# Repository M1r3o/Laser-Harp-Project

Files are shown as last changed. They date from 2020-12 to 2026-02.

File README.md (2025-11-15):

# Laser-Harp-Project
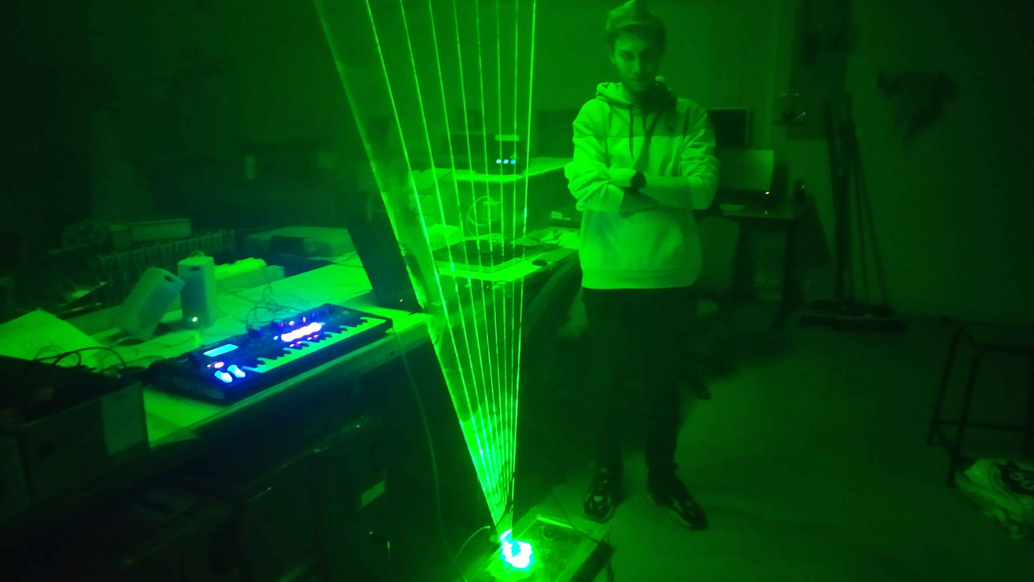
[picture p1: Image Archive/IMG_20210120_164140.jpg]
Laser Harp


This project was made in collaboration with Frederic_Wauters, Franck Morisseau A.K.A Genesis and Thomas Avisse, they helped me to understand the principle work of the laser harp . 

 This repository is a gather of all of my research, test , version, of Laser Harp     

/!\ The Light of Laser is very dangerous for the eyes, protect your eyes with a specific goggles /!\  

 This repository may not be complete but the main, schematics, code, plans and GERBER file is here to help you in this project.  

Disclaimer : some or any option ( example : strings vibration, RGB parametrable laser beam and the hand height) 
are inspired by french Laser Harp team : [there Laser Harp website](https://www.harpelaser.com) 
designed and conceived by (Franck Morisseau, Laurent Ma , and Other Laurent) 
But our electrical schematics, program, and pcb are not in relation with him and their team, just some option are inspired by their work 

Disclaimer #2 : WE ARE NOT RESPONSIBLE FOR BAD USAGE OF YOUR LASER, AND THIS REPOSITORY ARE NOT DELIVERED WITH ANY WARRANTY !!!

Thanks 

LH-Arduino Team 

## Demo of Laser Harp
### [Demo Laser Harp](https://youtu.be/7bUMFFDsR9I)

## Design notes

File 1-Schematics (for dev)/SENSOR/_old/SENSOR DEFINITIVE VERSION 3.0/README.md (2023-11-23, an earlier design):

For the sensor you have two choice (with same electronic board) 
- you can just use the dev version (but not sure their work correctly)
- or you can use the functionnal version which was tested (you need to print functionnal and dev version to compare which compoenent are removed, modify, or connected to the ground)

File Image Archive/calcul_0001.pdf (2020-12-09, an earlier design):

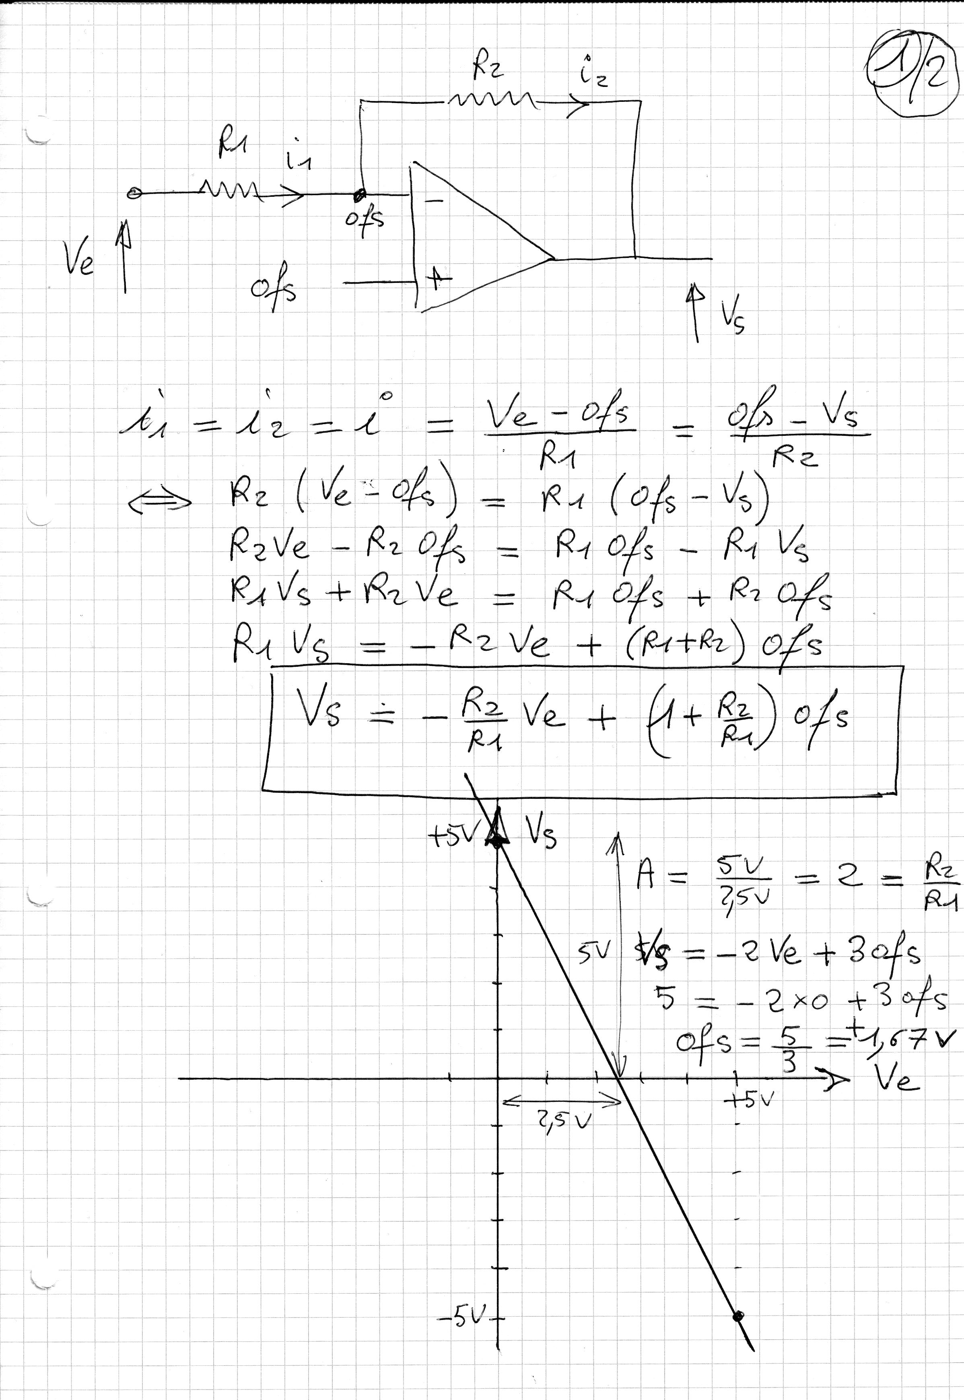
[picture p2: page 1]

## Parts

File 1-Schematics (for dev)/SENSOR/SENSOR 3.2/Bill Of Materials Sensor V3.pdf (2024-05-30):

## Bill Of Materials for Sensor V3

Design Title | Sensor V3

### Author Document Number Revision

Design Created | jeudi 28 avril 2022
Design Last Modified vendredi 23 février 2024

### Total Parts In Design 44

0 Modules
Quantity | References | Value | Stock Code | Unit Cost
Sub-totals: | | | | €0,00
22 Capacitors
Quantity | References | Value | Stock Code | Unit Cost
1 | C1 | 20pF
1 | C2 | 500nF
1 | C3 | 1nF
1 | C4 | 150nF
1 | C5 | 530nF
14 | C6-C7,C11-C22 | 100nF
3 | C8-C10 | 10uF
Sub-totals: | | | | €0,00
11 Resistors
Quantity | References | Value | Stock Code | Unit Cost
1 | R1 | 200k | M9K1
1 | R2 | 9k1 | M9K1
1 | R3 | 120k | M9K1
1 | R4 | 10k | M9K1
2 | R5-R6 | 1k | M9K1
3 | R7-R9 | 1K | M9K1
1 | R10 | 100K | M9K1
1 | R11 | 1M | M9K1
Sub-totals: | | | | €0,00
5 Integrated Circuits
Quantity | References | Value | Stock Code | Unit Cost
3 | U1,U4-U5 | TL082
1 | U2 | LM393
1 | U3 | ICL7660
Sub-totals: | | | | €0,00
0 Transistors
Quantity | References | Value | Stock Code | Unit Cost
Sub-totals: | | | | €0,00
3 Diodes
Quantity | References | Value | Stock Code | Unit Cost
1 | D1 | SLD70
1 | D3 | 1N4740A
1 | D4 | DIODE-SC
Sub-totals: | | | | €0,00
3 Miscellaneous
Quantity | References | Value | Stock Code | Unit Cost
1 | DB1 | DB9
1 | J1 | 27630302RP2 | NorComp 27630302RP2
1 | RV1 | 200K | Digikey 3252W-204LF-ND
Sub-totals: | | | | €0,00

Tot

als: | €0,0
| 0

ve

n

dre

di

2

| 3 fé vri
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
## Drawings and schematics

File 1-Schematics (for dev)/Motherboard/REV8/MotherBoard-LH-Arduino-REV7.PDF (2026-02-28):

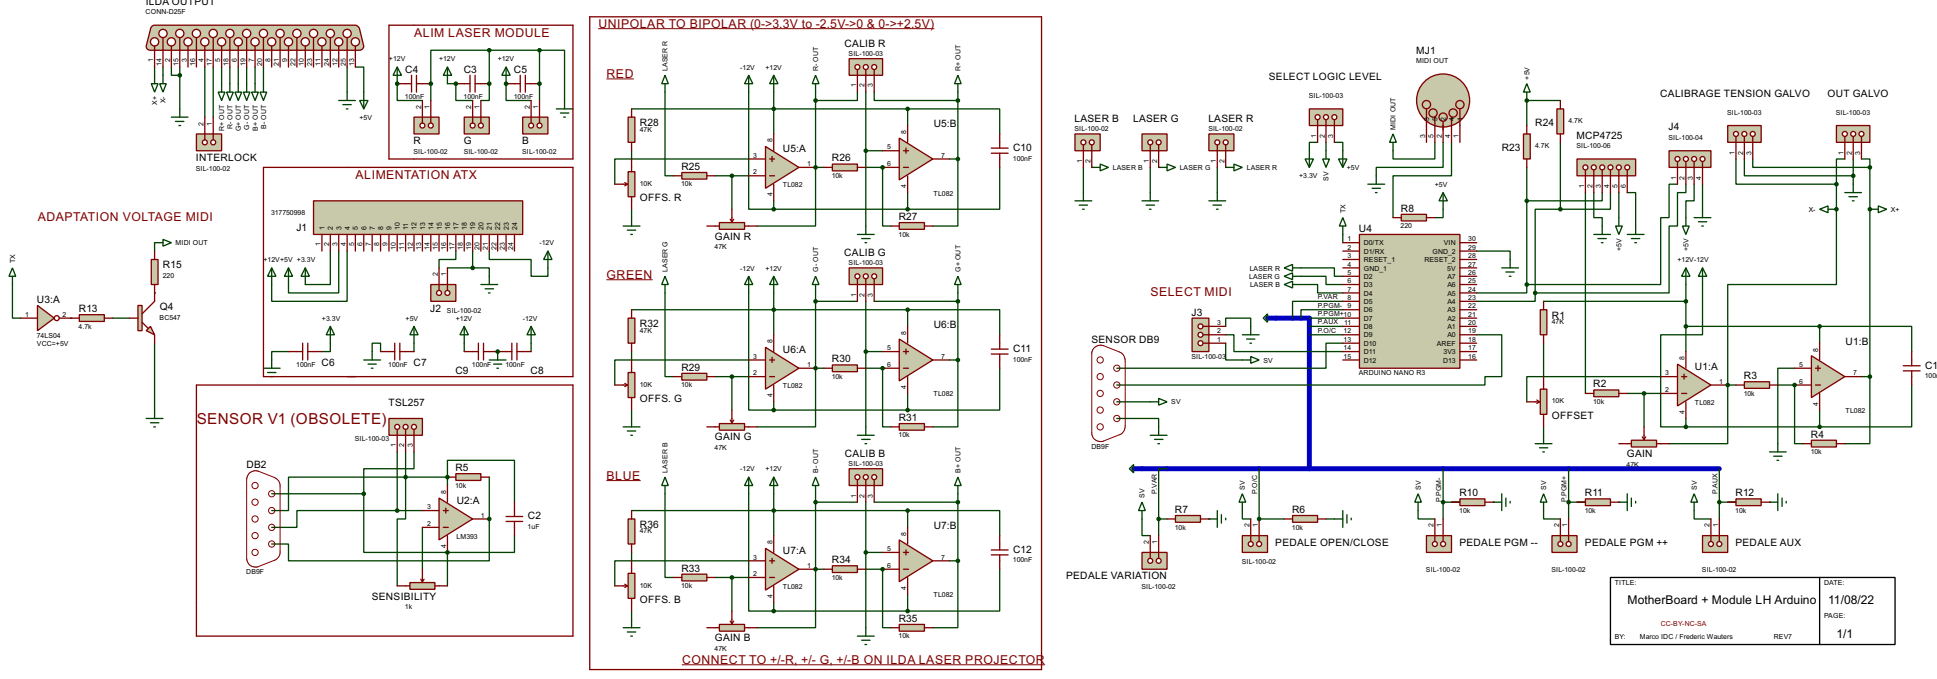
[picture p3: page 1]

UNIPOLAR TO BIPOLAR (0->3.3V to -2.5V->0 & 0->+2.5V)

GAIN B
CONNECT TO +/-R, +/- G, +/-B ON ILDA LASER PROJECTOR

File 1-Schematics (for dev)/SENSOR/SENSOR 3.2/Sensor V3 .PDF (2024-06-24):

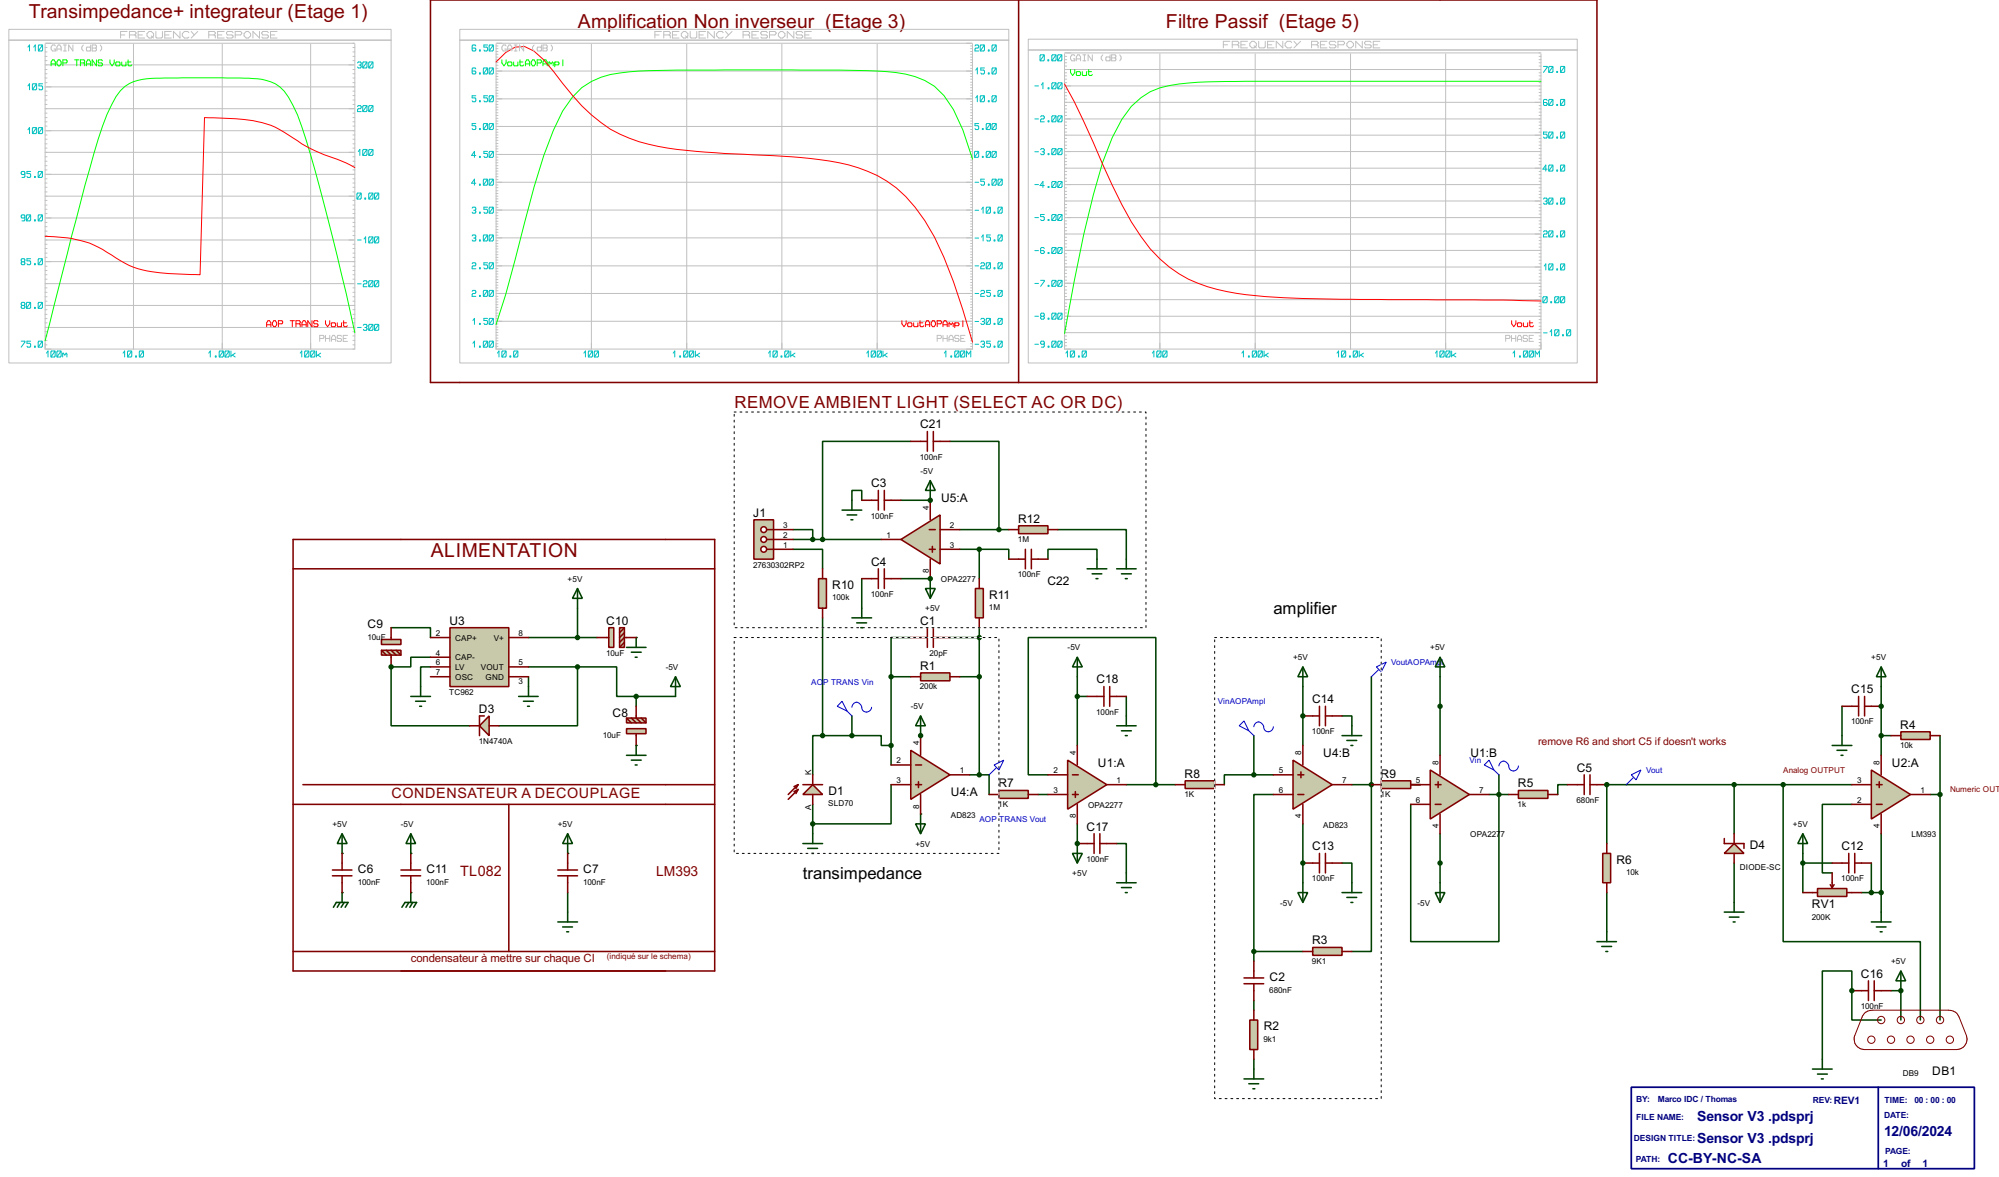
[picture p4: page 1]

REMOVE AMBIENT LIGHT (SELECT AC OR DC)

remove R6 and short C5 if doesn't works

(indiqué sur le schema)

condensateur à mettre sur chaque CI

DESIGN TITLE:Sensor V3 .pdsprj

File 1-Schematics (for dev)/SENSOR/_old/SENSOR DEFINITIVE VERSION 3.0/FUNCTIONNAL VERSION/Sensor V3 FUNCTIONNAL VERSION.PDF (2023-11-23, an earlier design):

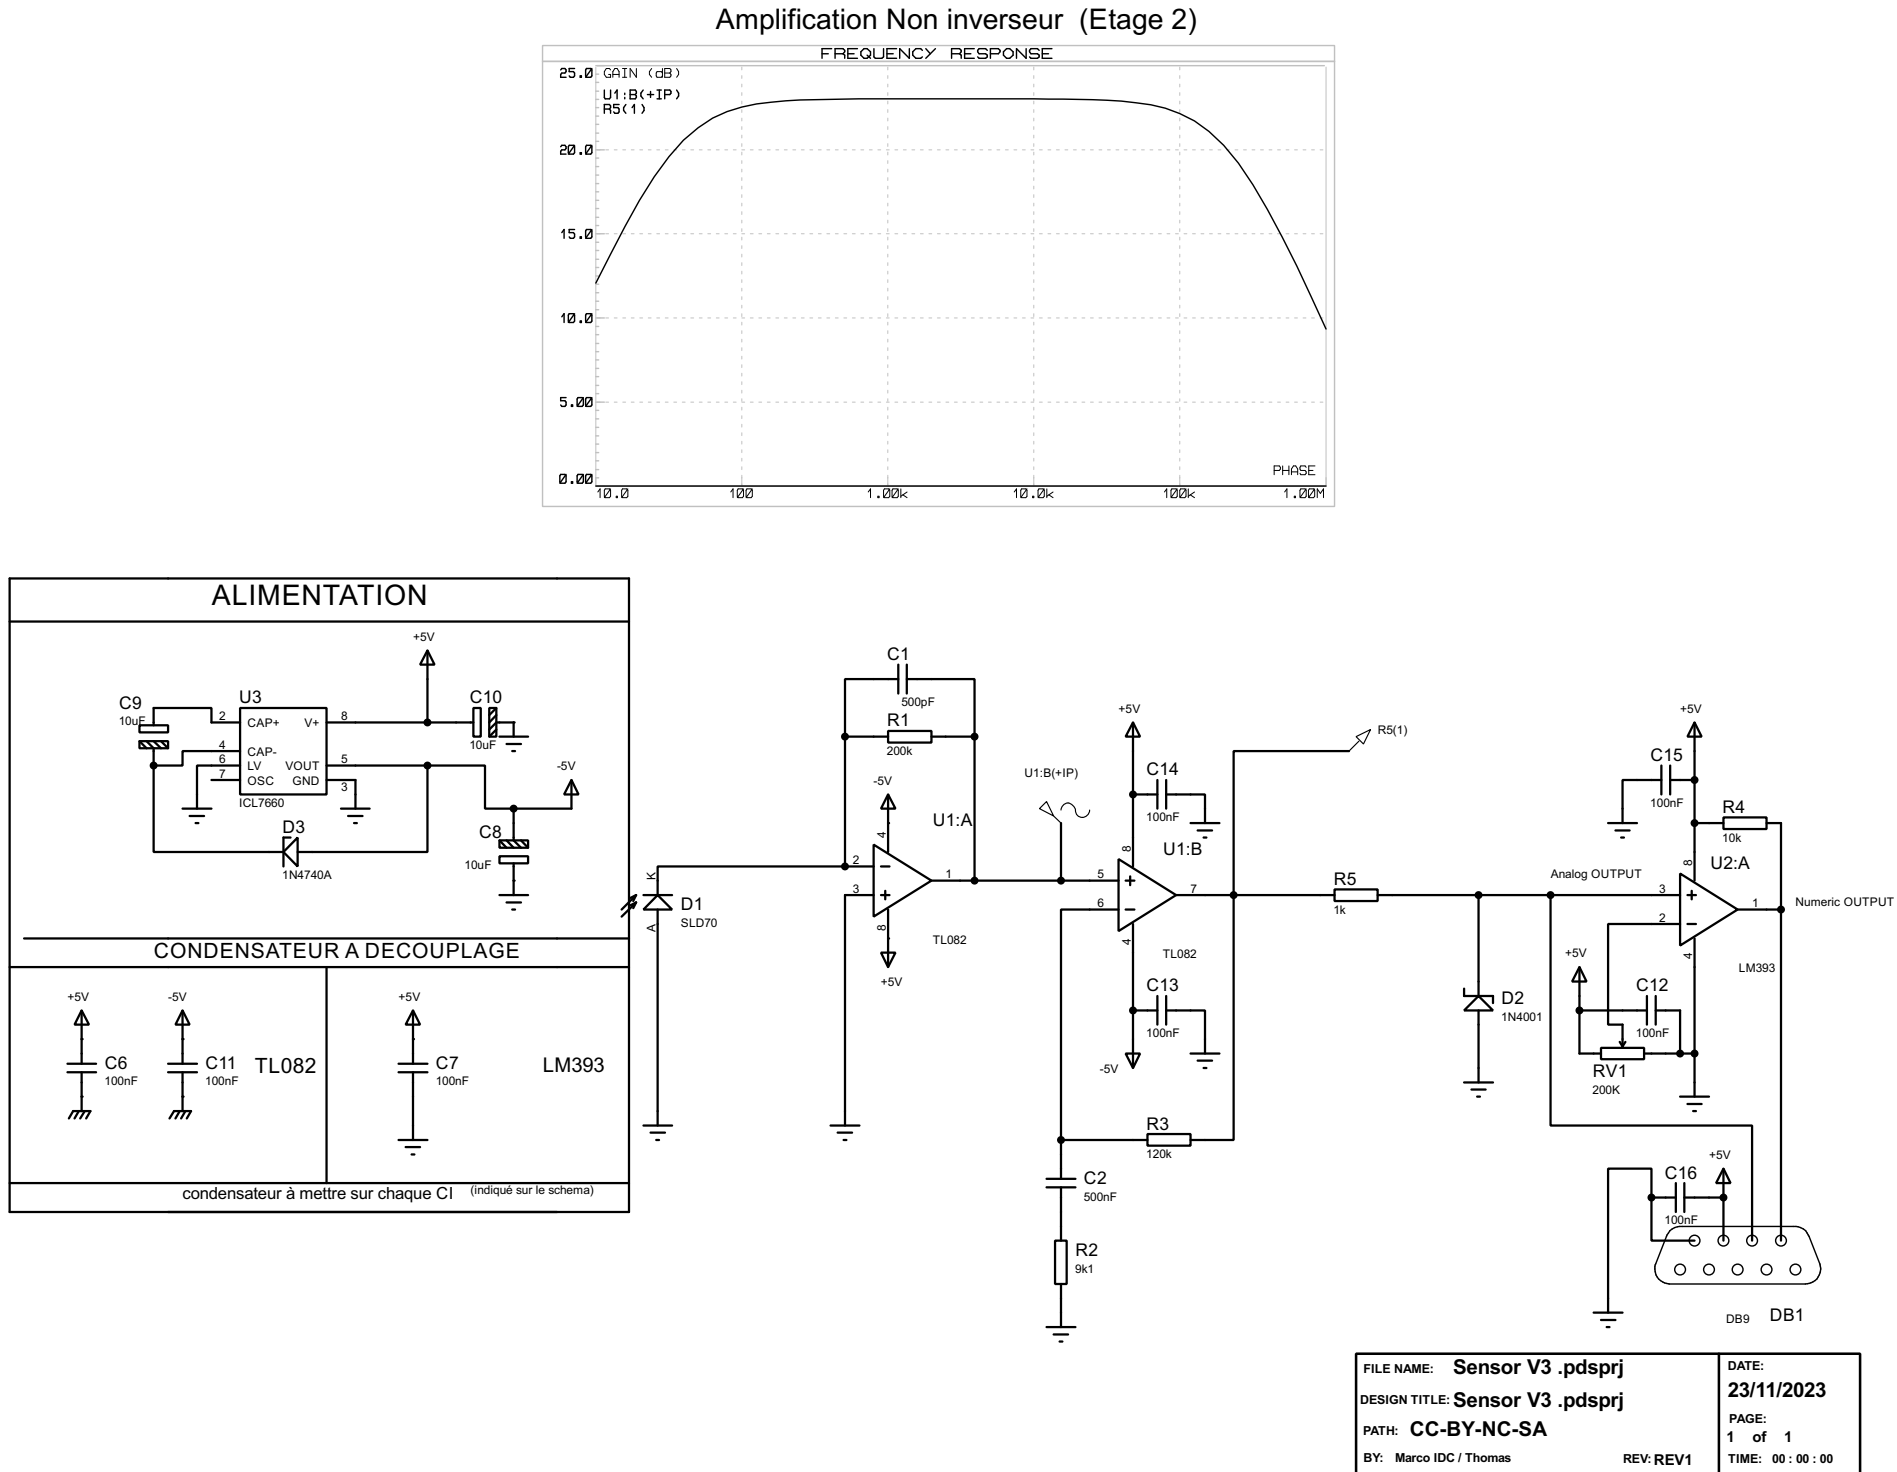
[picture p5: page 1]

Amplification Non inverseur (Etage 2)

condensateur à mettre sur chaque CI

(indiqué sur le schema)

FILE NAME:
DESIGN TITLE:Sensor V3 .pdsprj

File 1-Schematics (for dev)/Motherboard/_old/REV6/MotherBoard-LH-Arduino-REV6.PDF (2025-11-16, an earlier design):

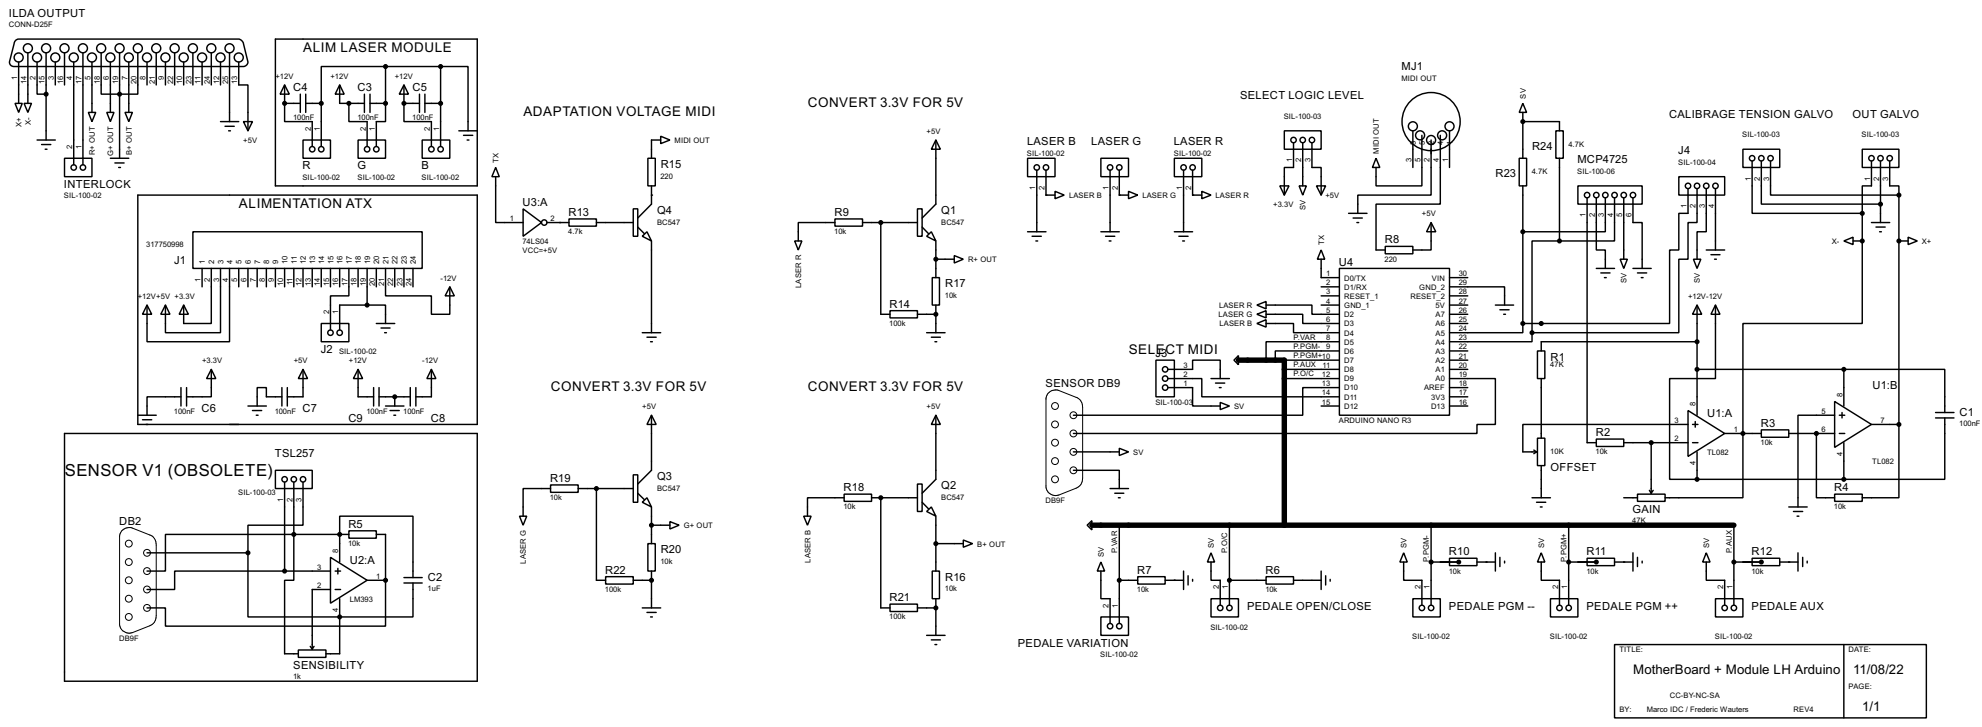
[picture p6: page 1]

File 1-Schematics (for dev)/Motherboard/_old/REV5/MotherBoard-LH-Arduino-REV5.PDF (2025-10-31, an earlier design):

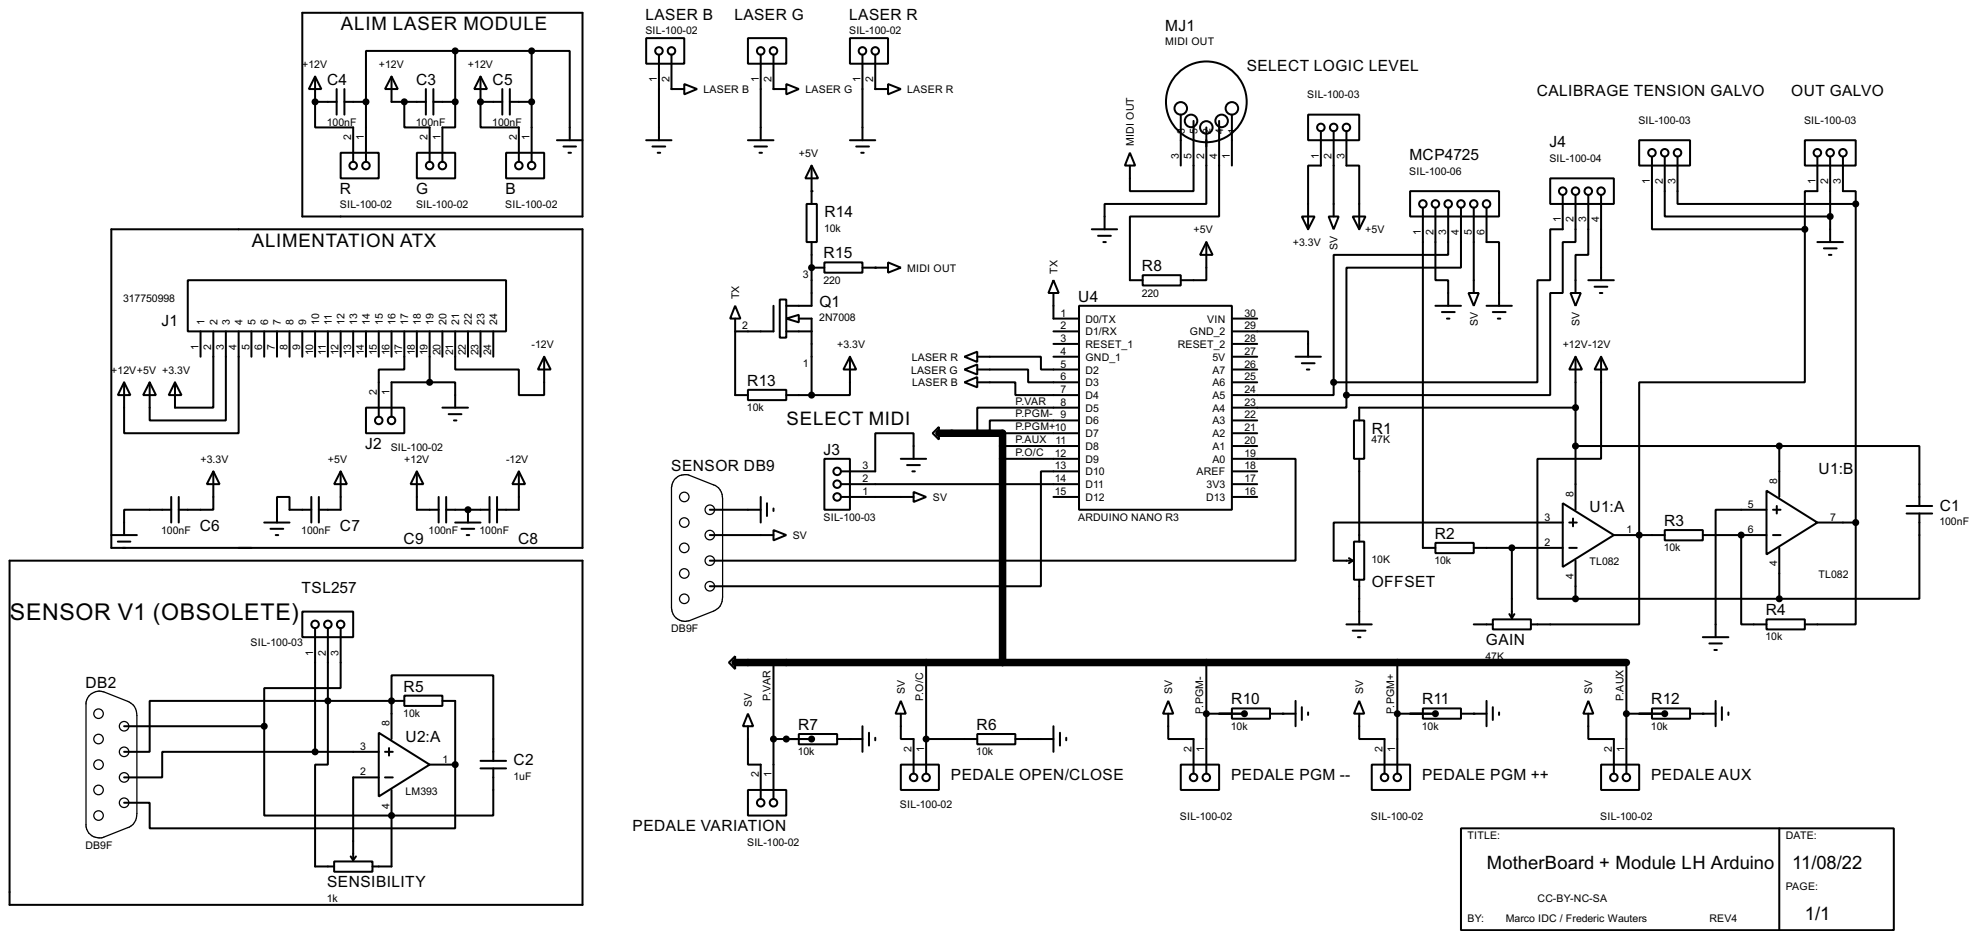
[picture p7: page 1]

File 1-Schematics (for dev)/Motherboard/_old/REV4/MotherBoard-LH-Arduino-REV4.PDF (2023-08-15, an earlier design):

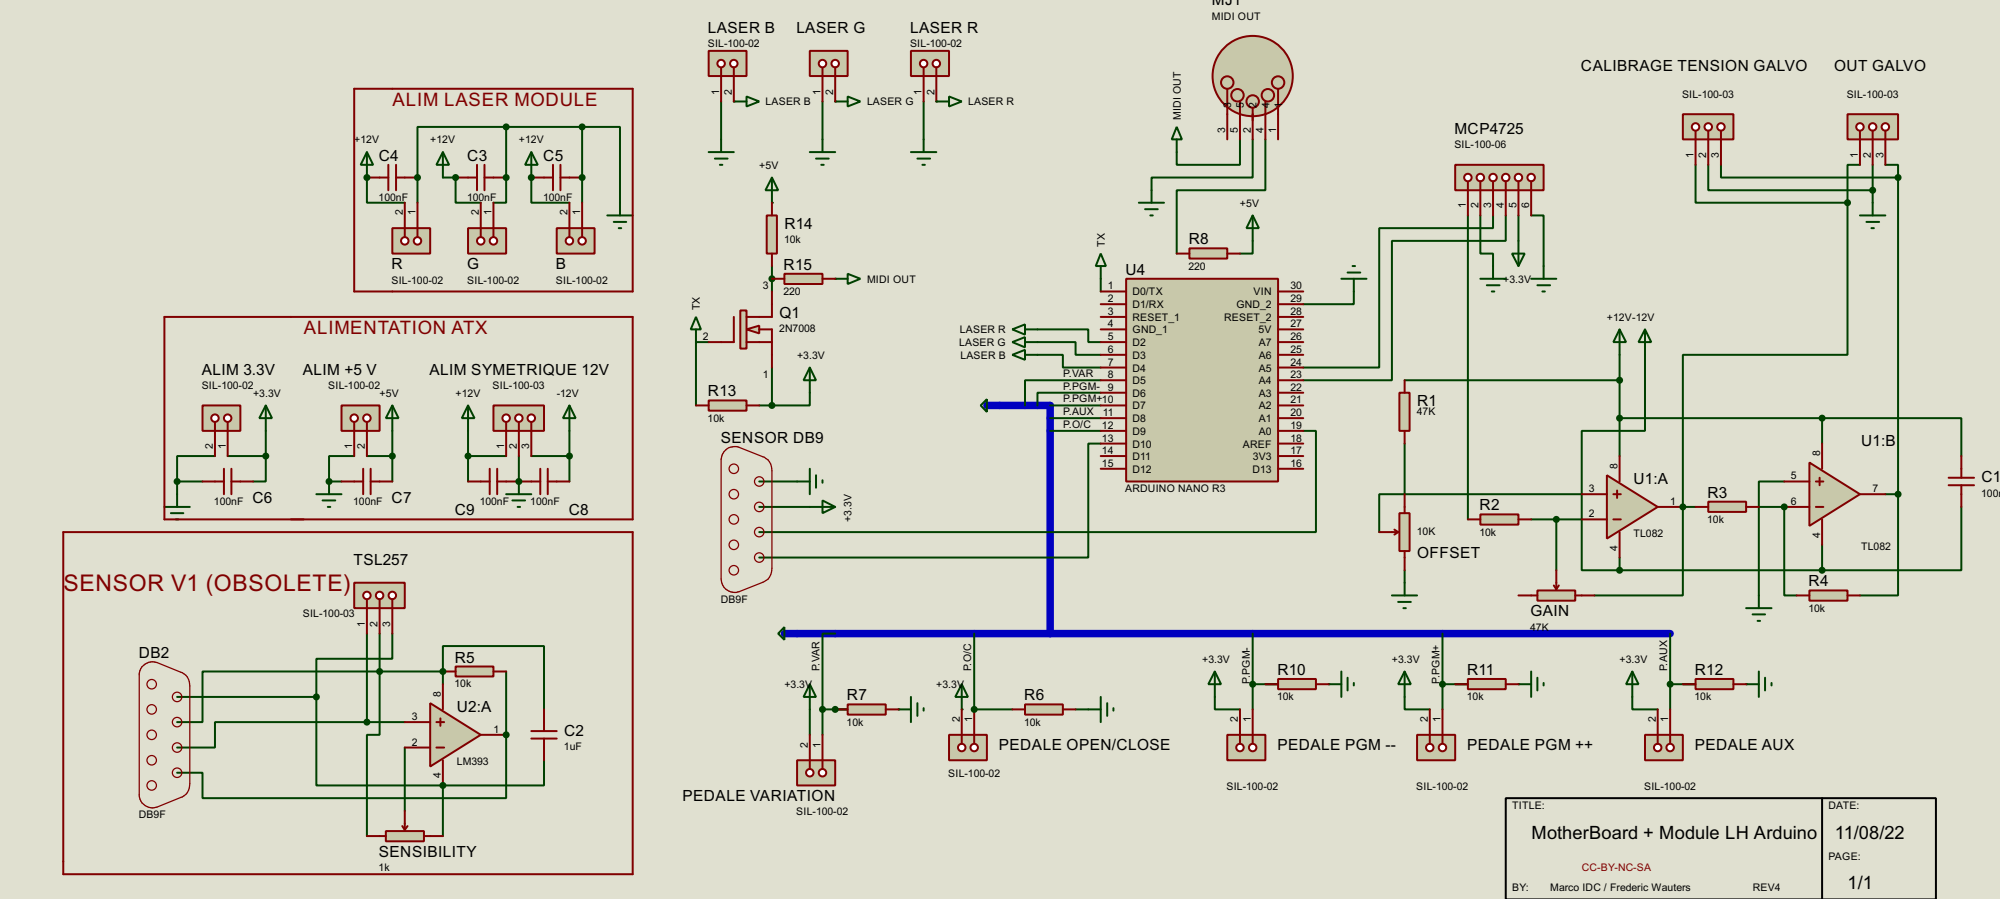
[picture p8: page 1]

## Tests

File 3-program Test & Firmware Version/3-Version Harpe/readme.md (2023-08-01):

## AVR => 8bit micro-controller be like ATMega 328p ATMega2560 (Arduino Uno, Mega, Nano ,Leonardo) 
## ARM => 32 Bit Micro controller be like ESP 32-S3,ARM M0+ (Nano 33IoT, Arduino DUE, and more). More feature for them, be like web server for UI configuration, RGB laser and other features

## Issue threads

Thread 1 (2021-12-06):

Just a question

laurence-diack, 2021-12-06:
What was the rationale behind choosing the LT1013 op-amp in particular? And what was your reason for abandoning the TSL257 in favour of a silicon diode? Do you find it performs noticeably better? I'm trying to make a sensor that compares filtered and unfiltered TSL250 sensors but I came across your project and it seems like an interesting approach

M1r3o, 2021-12-06:
I never have used LT1013 , i used for symetric command to galva a TL082 because he have better response and LM 393 because it's comparator OP-amp.  I use actually TSL 257 because it's simple to connect and manage, I have two OUTPUT , analog Output for height hand and second connected to my OP-amp to have a logic signal (level of saturation is managed by a potentiometer connected to 5V) . It's possible to filter the input signal (provided by the hand when cutting laser) with high pass or band pass filter . I actually work to make a sensor with filter ..

laurence-diack, 2021-12-06:
I was referring to the schematic in `Laser-Harp-Project/2-Sensor/LaserHarp_sensor-V03-final.pdf` though maybe thats out of date.

M1r3o, 2021-12-07:
this schematic was maked/buillt by my associated person , frederic wauters , this schematic include a band pass filter to exclude ambient/parasite light , but for me i have some problem , i need a symetric voltage input for OP-AMP , and i search a hight position of my hand, and with this schematic is not possible ..

M1r3o, 2021-12-07:
i have maked all in one plan for laser harp to make after a Mother Board  https://github.com/M1r3o/Laser-Harp-Project/tree/main/4-%20All%20In%20One%20electronic%20plan%20Laser%20Harp/REV2

M1r3o, 2021-12-08:
UPDATE : i upload new schematics with TSL257

M4N0J-KUM4R, 2024-02-28:
I am new to electronics but good in music and some codings but i want to build one myself can you help me by guiding from scratch. Because I can't afford $1500 dollers to buy one instead I can build one could you please help me!

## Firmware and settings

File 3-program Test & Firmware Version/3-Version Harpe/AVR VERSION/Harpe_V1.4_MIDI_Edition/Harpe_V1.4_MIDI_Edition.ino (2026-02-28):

//release by M1r3o & Frederic Wauters
//Creative Commons CC-BY-NC-SA 2021
//Harpe_V1.4_MIDI_Edition

// Created by Frederic Wauters and Istchenko de Carvalho Marco under Creative Commons Licence CC-BY-NC-SA
// This code is delivered with no warranties and you use it at your own risks.
// Version 1.0 - 2021-03-04 - F. Wauters Belgium - M . istchenko de Carvalho France

// PLEASE READ THIS IMPORTANT NOTICE
// SVP LISEZ CETTE NOTE IMPORTANTE
//
// About CC-BY-NC-SA...
// -----------------
// You CAN    : share, copy, redistribute, adapt, remix, transform and build using
//              the code.
//
// You CANNOT : use for commercial purposes.
//
// You CANNOT : apply legal terms or technological measures that legally restrict
//              others from doing anything the license permits.
//
// You MUST   : give appropriate credit, provide a link to the license, and indicate
//              if changes were made. You may do so in any reasonable manner, but not
//              in any way that suggests the licensor endorses you or your use.
//
// Complete informations about CC-BY-NC-SA licence :
//    https://creativecommons.org/licenses/by-nc-sa/2.0/be/deed.en
// Cree par Frederic Wauters et Marco Istchenko de Carvalho sous licence Creative Commons CC-BY-NC-SA
// Ce code est fourni sans aucune garantie et vous l'utilisez a vos risques et perils.
// Version 1.0 - 2021-03-04 - F. Wauters Belgium - M . istchenko de Carvalho France
//
// A propos de CC-BY-NC-SA
// --------------------
// Vous POUVEZ        : partager, copier, distribuer et communiquer le code par tous
//                      moyens et sous tous formats.
//
// Vous NE POUVEZ PAS : faire un usage commercial de ce code, tout ou partie le composant.
//
// Vous NE POUVEZ PAS : appliquer des conditions legales ou des mesures techniques qui
//                      restreindraient legalement autrui a utiliser le code dans les
//                      conditions decrites par la licence.
//
// Vous DEVEZ         : crediter le code, integrer un lien vers la licence et indiquer si
//                      des modifications ont ete effectuees au code. Vous devez indiquer
//                      ces informations par tous les moyens raisonnables, sans toutefois
//                      suggerer que l'Offrant vous soutient ou soutient la facon dont vous
//                      avez utilise son travail.
//
// Informations complètes concernant la licence CC-BY-NC-SA :
//    https://creativecommons.org/licenses/by-nc-sa/2.0/be/deed.fr


// /!\ to send notes , we have configured serial protocol to 115200 Bytes/seconds
// we used to send MIDI notes : Hairless MIDI Serial (to send MIDI notes from Arduino to Standalone Synthesizer via USB->MIDI converter)
// Enter into setup and choose 115200 bauds rates
// to change option (actually vibration corde and reverse mode for note, go to "settings.h"
// (: enjoy :)

//////////////////////////////
////////dependance///////////
//#include "Wire.h"
//#include "MCP4725.h"
#include <MCP4725.h>
#include "settings.h"
MCP4725 dac(0x60);    // DAC
// *********
// * SETUP *
// *********
void setup() {
  Serial.begin(115200);
  dac.begin();
  dac.setValue(2060);
  //dac.setValue(maxX - minX);
  // Le Setup sert principalement a configurer et
  // a initialiser le diverses choses qui regissent le projet.
  // Si on y fait tourner autre chose, c'est pour "preparer le terrain", rien d'autre
  // Initialisation des pins
  //Serial.println("CALIB I/O");
  pinMode(laserPin, OUTPUT);
  pinMode(boutonOpen, INPUT);
  pinMode(boutonClose, INPUT);
  pinMode(pinSensor , INPUT);
  //Serial.println("CALIB I/O DONE");
  digitalWrite(laserPin, HIGH);
  digitalWrite(5, LOW);
  digitalWrite(7, LOW);
  // Initialisation du DAC
  delay(500);
  digitalWrite(laserPin, LOW);
  digitalWrite(5, HIGH);
  digitalWrite(7, HIGH);
  delay(500);
  digitalWrite(laserPin, HIGH);
  digitalWrite(5, LOW);
  digitalWrite(7, LOW);
  // Initialisation du DAC
  delay(500);
  digitalWrite(laserPin, LOW);
  digitalWrite(5, HIGH);
  digitalWrite(7, HIGH);
  //Serial.println("INIT HARPE DONE");
 

}

// ********
// * LOOP *
// ********
void loop() {
  // Le loop est la partie qui est "rejouee" en permanence par l'Arduino.
  // C'est la raison de son nom. Lorsque tout y a ete execute, il recommence.
  reverse();
  vibration();
  //Serial.println(NOTE_MIDI);
  dac.setValue(2047);

  // Attendre qu'on appuie sur open
  while (digitalRead(boutonOpen) == LOW) {
    // On ne fait rien, on attend qu'on appuie
    // Cette boucle tourne tant que le bouton open n'est pas enfonce
  }

  // On a appuie, on allume le laser
  digitalWrite(laserPin, HIGH);
  laserStatut = true;                // on retient que le laser est allume

  // On attend un peu pour l'effet... enfin, si on veut
  delay(1000);

  // SEQUENCE D'OUVERTURE
  // On boucle pour un ecart de 0 jusque maximum. L'ecart = 4095/(nbCordes-1)
  for (int ecart = 0; ecart < ((maxX - minX) / (nbCordes - 1)); ecart++) {
    // PLACER LE GALVO
    // On boucle sur toutes les cordes pour placer chacune
    for (int cordeCourante = 0; cordeCourante < (nbCordes - 1); cordeCourante++) {
      // Eteindre le laser
      digitalWrite(laserPin, LOW);
      digitalWrite(5, LOW);
      digitalWrite(7, LOW);
      laserStatut = false;

      // Placer le galvo
      position_corde = (milieu - (ecart * nbCordes / 2)) + (cordeCourante * ecart);
      dac.setValue(position_corde);

      // Pause de stabilisation
      delay(pauseStabilisation);

      // Allumer le laser
      digitalWrite(laserPin, HIGH);
      digitalWrite(5, LOW);
      digitalWrite(7, LOW);
      laserStatut = true;

      // Pause persistence
      delay(pausePersistence);
    }
  }

  // La harpe est ouverte, on le retient
  harpeStatut =  true;

  // Attendre qu'on appuie sur open
  while (digitalRead(boutonOpen) == LOW) {
    // Ecart
    ecart = (maxX - minX) / (nbCordes - 1);

    // En attendant qu'on demande la fermeture, on dessine la harpe et ses faisceaux bien sur...
    // On boucle sur toutes les cordes pour placer chacune
    for (int cordeCourante = 0; cordeCourante < (nbCordes - 1); cordeCourante++) {
      // Eteindre le laser
      digitalWrite(laserPin, LOW);
      digitalWrite(5, LOW);
      digitalWrite(7, LOW);
      laserStatut = false;

      // Placer le galvo
      position_corde = (milieu - (ecart * nbCordes / 2)) + (cordeCourante * ecart);
      dac.setValue(position_corde+(Notes[cordeCourante][VIBRATION]));
      Notes[cordeCourante][VIBRATION] =-(Notes[cordeCourante][VIBRATION]/2);
      delay(pauseStabilisation);

      // Allumer le laser
      digitalWrite(laserPin, HIGH);
      digitalWrite(5, LOW);
      digitalWrite(7, LOW);
      laserStatut = true;
      if (digitalRead(pinSensor) == true && Notes[cordeCourante][FLAGON] == 0) {// Si la note etait jusqu'ici Off et que la detection pour la corde desire est faite
        // Il faut jouer la note (MIDI)
        noteOn(0x90, Notes[cordeCourante][NOTE_MIDI], 127);
        // On memorise que cette corde joue , pour ne pas la rejouer(diiiiing,diiiing,diiiiing, (2eme condition If)
        //ont tient la note (allumee), jusqu'a ce qu'on retire la main
        Notes[cordeCourante][FLAGON] = 1;
        Notes[cordeCourante][VIBRATION] = cordeVibration ; 
      }

      else if (digitalRead(pinSensor) == false && Notes[cordeCourante][FLAGON] == 1 ) {// Si la note etait jusqu'ici ON et que la detection pour la corde desire n'est plus satisfaite
        // Il faut arreter ,ou, ne pas de jouer la note (MIDI)
        //memoriser que cette note n'est plus jouee
        // On memorise que cette corde ne joue pas
        noteOn(0x90, Notes[cordeCourante][NOTE_MIDI], 0); // on envoie une note mais ayant une velocite de 0 , donc elle ne sera pas joue
        Notes[cordeCourante][FLAGON] = 0 ;
        



      }

      delay(pausePersistence);

    }
    delay(pausePersistence);
  }


  // Si on a quitte la boucle, c'est qu'on a demande la fermeture

  // SEQUENCE DE FERMETURE
  // On boucle pour un ecart maximum jusque 0. L'ecart = 4095/(nbCordes-1)
  for (int ecart = (maxX - minX) / (nbCordes - 1); ecart > 0; ecart--) {
    // PLACER LE GALVO
    // On boucle sur toutes les cordes pour placer chacune
    for (int cordeCourante = 0; cordeCourante < (nbCordes - 1); cordeCourante++) {
      // Eteindre le laser
      digitalWrite(laserPin, LOW);
      laserStatut = false;

      // Placer le galvo
      position_corde = (milieu - (ecart * nbCordes / 2)) + (cordeCourante * ecart);
      dac.setValue(position_corde);

      // Pause de stabilisation
      delay(pauseStabilisation);

      // Allumer le laser
      digitalWrite(laserPin, HIGH);
      laserStatut = true;

      // Pause persistence
      delay(pausePersistence);
    }
  }

  // Harpe fermee (et on eteint le laser)
  harpeStatut = false;
  digitalWrite(laserPin, LOW);
  laserStatut = false;                // on retient que le laser est allume

  // On est au bout du LOOP, l'Arduino va recommencer. Il attend donc qu'on appuie a nouveau sur Ouvrir...
}

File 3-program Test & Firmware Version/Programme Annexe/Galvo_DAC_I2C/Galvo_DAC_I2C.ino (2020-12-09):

#include <MCP4725.h>

// Declarations
MCP4725 dac(SDA, SCL);
int nbCordes = 9;
int laserPin = 4;

// Configuration avant programme principal
void setup() {
  // Initialisation du DAC
  dac.begin();

  // Iitialisation des pins
  pinMode(laserPin, OUTPUT);
  digitalWrite(laserPin, HIGH);
   dac.setValue(2030);
   digitalWrite(laserPin, HIGH);
   delay(4000);
}

// Programme principal (boucle)
void loop() {
  // Variables de travail
  int laCorde = 0;
  
  // Boucler sur les cordes
  for (laCorde=0 ; laCorde<4095 ; laCorde = laCorde + (4096/nbCordes)) {
    // Valeur du dac
    dac.setValue(laCorde);

    // Pause stabilisation galvo
    delay(1);

    // Laser On
    digitalWrite(laserPin, HIGH);

    // Pause persistence retinienne
    delay (1);

    // Laser Off
    digitalWrite(laserPin, LOW);
  }
}
